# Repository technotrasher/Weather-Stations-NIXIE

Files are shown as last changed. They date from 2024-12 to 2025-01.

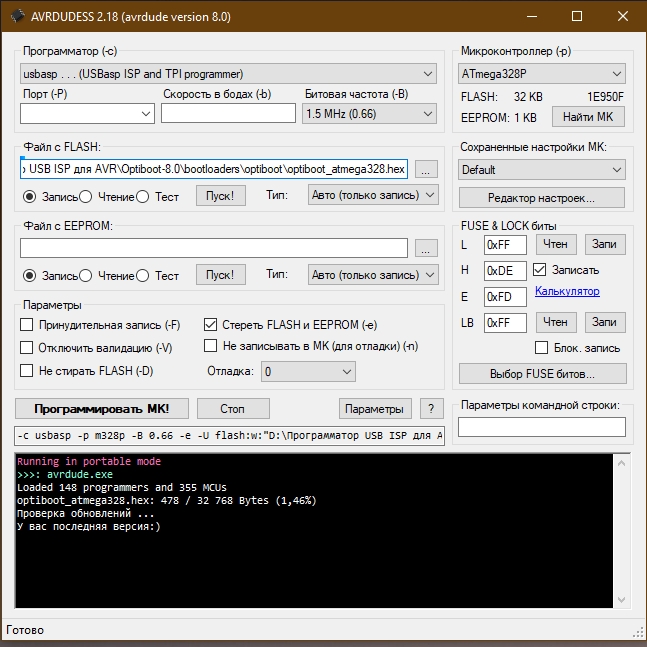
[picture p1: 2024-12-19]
328P_optiboot/1.jpg

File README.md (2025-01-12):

Проект Часы на ГРИ - погодная станция.

Одна плата управления. универсальна под разные лампы. и платы для ламп.

платы тут https://easyeda.com/technotrasher/nixie_clock_pcb_in14

Функции: показ времени :), отображение температуры, влажности, давления и СО2. Возможность подключения выносного датчика DS18B20. основной - BME280.

С помощью ESP-M2 есть возможность синхронизации времени через WI-FI.

Будильник с мерзким звуком. звук нажатия кнопок. звук можно настроить в самом скетче. буззер ставить БЕЗ ГЕНЕРАТОРА на 5В! (отличные результаты с LD-BZPN-3510)

Посветка из 6 программируемых свветодиодов ws2812. устанавливаются на платы для ламп. своих посадочных мест не имеют. можно размещать по своему усмотрению. RGB не подходят!!!!

7 вариантов работы:

Клик по кнопке btnUp переключает режимы подсветки ламп

    - выключена
    
    - выключена, но данные с датчиков подсвечиваются
    
    - постоянный свет
    
    - палитра PartyColors
    
    - палитра RainbowStripeColors
    
    - палитра CloudColors
    
Так же в режимах отображения информации своя подсветка:

    - режим отображения СО2 - ppm больше 1000, то цвет ярко красный
    
    - отображение давления - синий цвет всех светодиодов
    
    - влажность - ниже 32% цвет зеленовато-желтый, 32-40 - желтый, больше 40 - изумрудный
    
    - температура ниже нуля - цвет первых двух светодиодов синий
    
    - температура с датчика выносного DS - первый светодиод голубой.
      
   Есть эффекты переключения цифр:
   
Клик по кнопке btnDwn переключает режимы перелистывания цифр отображения часов и минут во время их смены:

      - Без эффекта
      
      - Плавное угасание
      
      - Перемотка по порядку числа
      
      - Перемотка по катодам
      
      - Поезд
      
      - Резинка
      
      - Блики
      
      - Перемотка со смещением
      
 Клик по кнопке btnSet переключает режимы перелистывания цифр секунд:
 
      - Без эффекта
      
      - Плавное угасание
      
      - Перемотка по порядку числа
      
Удержание кнопки btnUp:

      - показ даты.
      
для возврата удержать кнопку повторно.

Так же присутствуют глюки и эффекты. не отключаются. проявляются рандомно.

    - поезд
    
    - перепад напряжения
    
    - перебор катодов
    
    - неизвестно что

Основная плата выполненна на  AT328p. B неё нужно прошить загрузчик. я рекомендую optiboot.

В папке 328P_optiboot программа, сам загрузчик и скрин с настройками.
Загружать через программатор и разъем ISP на плате. после чего загружать скетчи можно через arduino ide и разъем USB.
Как вариант загружать можно скетч и через программатор. как подсоединять программатор, как загружать скетч описывать не буду.
все есть в интернете

При прошивке скетча отключать модуль ESP с помощью джамперов. !!!!!!!!!!!!!!!!!!!!!

ESP-2M обязательно обновить версию ПО. 

https://wiki.sipeed.com/soft/maixpy/en/get_started/upgrade_esp8285_firmware.html

в папке programm_esp есть программа, скрин с настройками и само ПО.

для прошивки нужен конвертер USB-TTL CH340G. или любой другой подходящий.
после загрузки ПО обязательно перевести модуль в режим точки клиента WI-Fi командой AT+CWMODE_DEF=1
о работе с модулями ESP так же есть вся информация в интернете.

После сборки выставить потенциометр на середину! крайние положения не выставлять! после подключить лампы и контролируя напряжение
на конденсаторе установить 175-180В!!!

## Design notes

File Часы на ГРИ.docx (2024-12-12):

Часы на ГРИ (Газо-Разрядных Индикаторах) Версии V1 и V2 (1999 г.)

Инструкция по эксплуатации.

ВНИМАНИЕ! После включения не дотрагивайтесь до компонентов и токоведущих дорожек платы, схема находится под высоким напряжением порядка 180В. Данное напряжение требуется для питания ламповых индикаторов. Будьте внимательны, соблюдайте правило работы с высоким напряжением.

### Особенности

- Режим антиотравления катода (перед сменой минут происходит быстрый перебор всех цифр во всех лампах)
- Будильник
- Сигнал каждый час
- Отображение температуры и влажности
- Отображение давления в мм ртутного столба
- Отображение содержания СО2 в ppm (parts per million — частей на миллион — единица измерения концентрации) (только для версии v1)
- Для каждого отображения или его критического значения разработана своя световая индикация. Так – давление (синий цвет), температура-влажность: влажность меньше 32% – цвет тёмно-красный, от 32 до 40 % влажности желто-зелёный, больше 40% - изумрудно зелёный, содержание СО2 – белый цвет до 1200 ppm и красный более 1200 (СО2 только для версии v1)
- При включении прибора происходит перебор анодов и катодов индикаторов
- Ночная и дневная яркость, как подсветки, так и индикаторов
- Настройка времени и будильника
- Отключение, переключения режимов подсветки кнопкой
- Переключение эффектов смены цифр кнопкой (только для версии v2)

Газоразрядные индикаторы ИН-14 (ИН-12 для версии v2) производились в прошлом веке и использовались для отображения информации (цифровой, символьной), на основе тлеющего разряда. В настоящее время данные лампы используются для создания часов.

Часы имеют энергонезависимую память на модуле DS1302 RTC - в комплект входит батарейка CR2032, или акб для V1.

Управление часами происходит тремя кнопками. С помощью кнопки "SET (S для V2)" происходит перебор режимов. Переход часы, будильник, отображение времени – длительное нажатие (2 секунды). С помощью кнопок установки значения “+”,”-” происходит смена значения в том или ином режиме. Перемещение между индикаторами – краткое нажатие кнопки “SET” (менее 1 секунды). Тумблер, позиция вверх - включает сигнал будильника, вниз – отключает. Сигнал так же отключится при переходе часов в режим показа давления и т.д. Отключение/включение подсветки – длительное нажатие (2 секунды) кнопки “+” (для версии V1). Переключение режимов подсветки – нажатиями кнопки “L” (постоянный свет, градиент теплый, радуга, градиент холодный, отключение подсветки) для V2. Переключение режимов смены цифры – кнопка “E”, переключаемые режимы сопровождаются соответствующей индикацией. Режимы – перебор катодов, затухание, резинка, поезд, выключено.

Во время настройки времени – секунды продолжают идти!

Конструктивно устройство выполнено на двух печатных платах из фольгированного стеклотекстолита. Расстояние между соединенными платами – 15 мм. Не надавливайте на верхнюю плату с лампами во время работы прибора, это приведёт к КЗ!!!!

Раз в 30 минут, когда происходит смена знака, включается режим антиотравления катода ламп. В этот момент происходит перебор всех знаков в каждом индикаторе, что делает работу часов еще более эффектнее. Время перебора измеряется в миллисекундах и визуально не заметна.

Часы запрограммированы на различные эффекты, которые разбавят монотонное отображение времени на индикаторах. Эффекты – Глюк (яркостной дребезг индикатора, в том числе и точек), Поезд (убегание показаний индикации времени), Перебор индикаторов (перебор анодов и катодов, но в соответствии с установленной суточной яркостью). Время срабатывания эффектов задаётся неопределённо (rnd) - и станет сюрпризом.

При отключении часов от эл. питания и последующем включении – время не сбивается!!!

В задней стенке часов находятся датчики. Или датчик BME220 для V2

Часы запрещается эксплуатировать в запыленном и влажном (более 90% влажности) воздухе. А также избегать попадание воды на прибор.

Как заводить часы?

Изначально они заводятся на 35-40 оборотов. Современные механизмы сделаны таким образом, что часы «перезавести» невозможно. Но это не значит, что крутить заводную головку можно до фанатизма. При полном заводе они проработают 36-40 часов в зависимости от механизма.

Монтаж часов:

1 Освободите молоточки от упаковки

2 Подвесьте маятник

Достаньте маятник из упаковки, снимите защитную пленку, аккуратно подвесьте его на крючок, который находится за механизмом.

3 Подвесьте гири

Освободите цепи от упаковки. Часы должны стоять прямо, чтобы избежать цепи соскочили с механизма. Если у часов три гири, необходимо последовательно подвесить их на цепи. Если гирь нет, значит их украли.

4 Запустите механизм

Завести механизм часов, аккуратно раскачивая маятник. Через несколько минут маятник обретет нужную скорость, и Вы услышите регулярных ход часов «тик-так».

Не забывайте кормить кукушку!

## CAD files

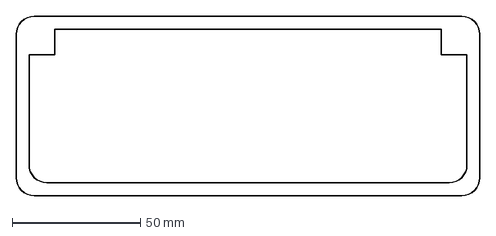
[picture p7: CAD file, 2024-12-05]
model/корпус12/кольцо лицо 4.dxf
181.0 x 70.0 mm

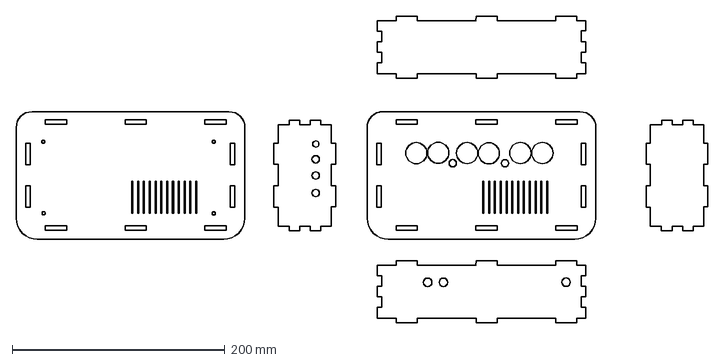
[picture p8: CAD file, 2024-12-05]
model/корпус3/корпус3.dxf
650.3 x 288.2 mm

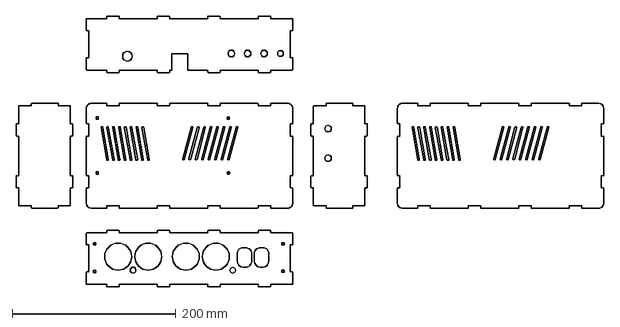
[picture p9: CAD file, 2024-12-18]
model/корпус4/корпус 4.dxf
717.6 x 330.7 mm

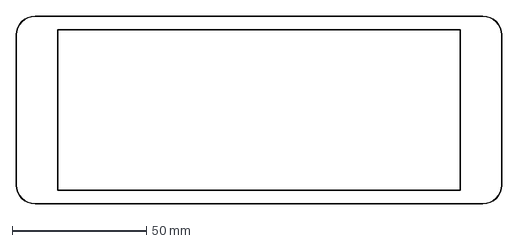
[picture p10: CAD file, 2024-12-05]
model/корпус12/кольцо лицо 1.dxf
181.0 x 70.0 mm

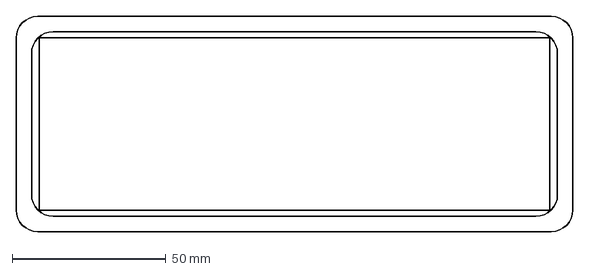
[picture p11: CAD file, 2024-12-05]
model/корпус12/кольцо лицо главное.dxf
181.0 x 70.0 mm

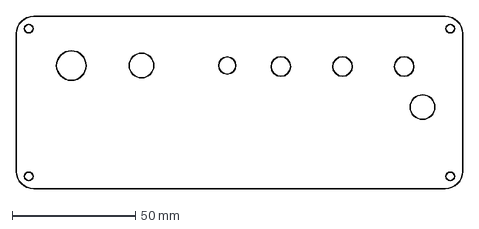
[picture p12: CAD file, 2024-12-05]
model/корпус12/крышка зад.dxf
181.0 x 70.0 mm

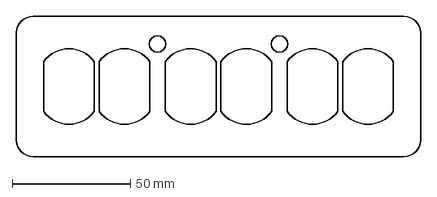
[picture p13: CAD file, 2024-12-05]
model/корпус12/панель перед.dxf
170.9 x 59.4 mm

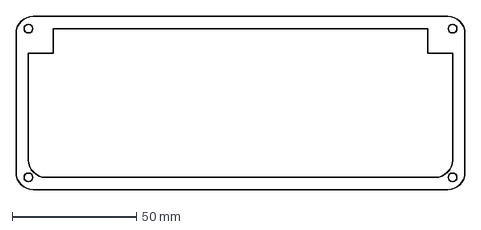
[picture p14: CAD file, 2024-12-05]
model/корпус12/кольцо лицо жопа.dxf
181.0 x 70.0 mm

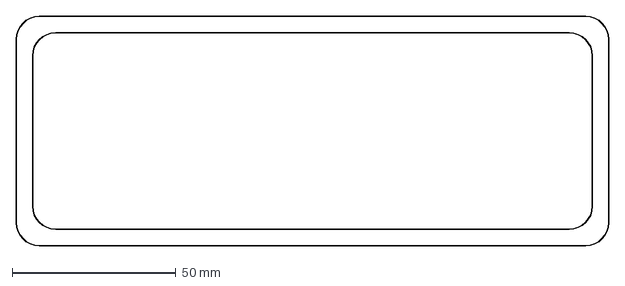
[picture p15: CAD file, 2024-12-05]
model/корпус12/кольцо лицо 6.dxf
181.0 x 70.0 mm

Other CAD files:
model/korpus3.dwg
model/корпус12/кольцо лицо 1 v3.f3d
model/корпус12/кольцо лицо 4 v3.f3d
model/корпус12/кольцо лицо 6 v3.f3d
model/корпус12/кольцо лицо главное v3.f3d
model/корпус12/кольцо лицо жопа v3.f3d
model/корпус12/крышка зад v6.f3d
model/корпус12/панель перед v9.f3d
model/корпус3/korpus3 v29.f3d
model/корпус4/корпус 4 v22.f3d

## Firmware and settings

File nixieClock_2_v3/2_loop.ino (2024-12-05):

void loop() {
  if (dotTimer.tick() && (stat_mode == Clock || stat_mode == ClockSet || stat_mode == AlarmSet || stat_mode == DataSet || stat_mode == DataSetY)) calculateTime();                  // каждые 500 мс пересчёт и отправка времени
  if (newTimeFlag && stat_mode == Clock) flipTick(); //включение эффектов при переходе через минуту и час
  if (newTimeFlagsec && stat_mode == Clock) Ticksec(); // эффект секунды                                                                                                                                // перелистывание цифр
  dotBrightTick();                                                                                                                                                                  // плавное мигание точки
  if ((SHOW_GL && stat_mode == Clock) || stat_mode == Temperature || stat_mode == Pressure || stat_mode == CO2) glitchTick();                                                       // глюки
  buttonsTick();                                                                                                                                                                    // кнопки
  settingsTick();                                                                                                                                                                   // настройки
  pwm();                                                                                                                                                                            // данные с датчика СО2 MHZ19
  if (SHOW_ESP && !alm_flag && ef_flag && ESPTimer.tick()) realtime();                                                                                                              // синхронизация времени через WIFI
  if (stat_mode > 8 || curMode > 4) resetFunc();                                                                                                                                    // перезагрузка при глюке ака костыль  4 режим
  if ((SHOW_TEMP_HUM || SHOW_TEMP_DS) && !alm_flag && ef_flag && stat_mode != AlarmSet && stat_mode != ClockSet && stat_mode != DataSet && stat_mode != DataSetY) stat_modeTick();  //температура влажность
  if (SHOW_CO2 && !alm_flag && ef_flag && stat_mode != AlarmSet && stat_mode != ClockSet && stat_mode != DataSet && stat_mode != DataSetY) stat_modeTickCO();                       // СО2
  if (SHOW_PRES && !alm_flag && ef_flag && stat_mode != AlarmSet && stat_mode != ClockSet && stat_mode != DataSet && stat_mode != DataSetY) stat_modeTickP();                       // отображать давление
  if (SHOW_TR && !alm_flag && ef_flag && stat_mode != AlarmSet && stat_mode != ClockSet && stat_mode != DataSet && stat_mode != DataSetY) train_Event();                            //поезд.
  if (SHOW_TEST && !alm_flag && ef_flag && stat_mode != AlarmSet && stat_mode != ClockSet && stat_mode != DataSet && stat_mode != DataSetY) TestTimerI();                           //перебор индикаторов. тут можно отключить
  if (stat_mode == Clock && !alm_flag) {
    LEDsFromColors();  // установить подсветку
  }
}

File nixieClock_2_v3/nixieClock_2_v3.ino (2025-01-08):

/*
  Скетч к проекту "Часы на ГРИ версия 3.5"
  платы тут https://easyeda.com/technotrasher/nixie_clock_pcb_in14
*/

/*
                       При прошивке скетча отключать модуль ESP!!!!!!!!!!!!!!!!!!!!!!
  Управление:
  - Настройка времени:
    - Левая кнопка - выбор, остальные "больше" и "меньше"
    - Удержать "выбор" первый раз btnSet - настройка времени
    - Клик по "выбору" btnSet - смена настройки часы/минуты
    - Клик "больше" и "меньше" - изменение времени
    - Удержать "выбор" второй раз - настройка будильника
    - Левая кнопка - выбор, остальные "больше" и "меньше"
    - Удержать "выбор" третий раз - установка даты и месяца
    - Удержать "выбор" четвертый раз - установка года
    - Удержать "выбор" btnSet - настройка времени
    - Клик по "выбору" btnSet - смена настройки часы/минуты
    - Клик "больше" и "меньше" - изменение времени
    - Удержать "выбор" - возврат к показу времени
    - Удержание "больше" - отображение даты. вид - день. месяц. день недели. для выхода нажать и удержать повторно

    В модуле ESP в строке 58 указать свои настройки. имя точки вайфай и пароль к точке доступа. кавычки не трогать.
    В библиотеке wire - если на плате нет подтяжки пинов A4 A5 к vcc через резисторы 4.7кОм, то заменить строку
  PORTC &= 0xCF; //отключаем подтяжку SDA и SCL
  на строку
  PORTC |= 0x30; //включаем подтяжку SDA и SCL

  Подсветка
  1. режим отображения СО2 - ppm больше 1000, то цвет ярко красный
  2. отображение давления - синий цвет всех светодиодов
  3. Влажность - ниже 32% цвет зеленовато-желтый, 32-40 - желтый, больше 40 - изумрудный
  4. температура ниже нуля - цвет первых двух светодиодов синий
  5. температура с датчика выносного DS - первый светодиод голубой
 

  - Управление эффектами В РЕЖИМЕ ЧАСОВ:
    - Клик по кнопке btnUp переключает режимы подсветки ламп
    - выключена
    - выключена, но данные с датчиков подсвечиваются
    - постоянный свет
    - палитра PartyColors
    - палитра RainbowStripeColors
    - палитра CloudColors
    - Клик по кнопке btnDwn переключает режимы перелистывания цифр
      - Без эффекта
      - Плавное угасание
      - Перемотка по порядку числа
      - Перемотка по катодам
      - Поезд
      - Резинка
      - Блики
      - Перемотка со смещением

  Удержание кнопки btnUp
  - показ даты.
  для возврата удержать кнопку повторно

  Удержание кнопки btnDown
  - отключает запрос времени из интернета через модуль ESP (изначально включено) 0 = SHOW_ESP - выкл. 1 = SHOW_ESP - вкл
 
  Двойной клик по btnUP - смена часового пояса. работает только при работе модуля ESP
  после двойного нажатия - сигнал длиннее прозвучит (1 = esptime - лето 0 = esptime - зима)
  Одинарный клик по btnSet - включение/отключение эффекта секунд без эффекта, угасание, перемотка


*/
// ************************** НАСТРОЙКИ **************************
#define DUTY 190  // скважность ШИМ. От скважности зависит напряжение! у меня 175 вольт при значении 180 и 145 вольт при 120

// ======================= ЭФФЕКТЫ =======================
// эффекты перелистывания часов
uint8_t FLIP_EFFECT = 1;
// Выбранный активен при запуске и меняется кнопками
// 0 - нет эффекта
// 1 - плавное угасание и появление (рекомендуемая скорость: 100-150)
// 2 - перемотка по порядку числа (рекомендуемая скорость: 50-80)
// 3 - перемотка по порядку катодов в лампе (рекомендуемая скорость: 30-50)
// 4 - поезд (рекомендуемая скорость: 50-170)
// 5 - резинка (рекомендуемая скорость: 50-150)
// 6 - блики (рекомендуемая скорость: 80-250)
uint8_t FLIP_SPEED[] = { 0, 100, 100, 50, 70, 70, 150, 70 };  // скорость эффектов, мс (количество не меняй) 0, 130, 50, 40, 70, 70, 200, 90

// эффекты подсветки
uint8_t BACKL_MODE = 1;
// Выбранный активен при запуске и меняется кнопками
// 0 - выключена полностью
// 1 - выключена, но работает при отображении СО2 и т.д.
// 2 - постоянный свет
// 3 - радуга
// 4 - градиент
// 5 - рандомный цвет
// 6 - волна
// 7 - дыхание
// 8 - бегущий огонь

// =======================  ЯРКОСТЬ =======================
#define NIGHT_START 22  // час перехода на ночную подсветку (BRIGHT_N)
#define NIGHT_END 8     // час перехода на дневную подсветку (BRIGHT)

#define INDI_BRIGHT 22   // яркость цифр дневная (1 - 24) !на 24 могут быть фантомные цифры! 23
#define INDI_BRIGHT_N 7  // яркость ночная (1 - 24) 5
uint8_t SHOW_SEC = 0;   // переключение эффектов секунд. 0 -  выключен

#define DOT_BRIGHT 70    // яркость точки дневная (1 - 255) 80
#define DOT_BRIGHT_N 25  // яркость точки ночная (1 - 255)

#define BACKL_BRIGHT 80    // макс. яркость подсветки дневная (0 - 255) 80
#define BACKL_BRIGHT_N 30  // макс. яркость подсветки ночная (0 - 255, 0 - подсветка выключена)
//https://colorscheme.ru/color-converter.html

// =======================  ГЛЮКИ =======================
#define GLITCH_MIN 30   // минимальное время между глюками, с
#define GLITCH_MAX 120  // максимальное время между глюками, с

#define train_MIN 300  // минимальное время между поездом, с 180
#define train_MAX 600  // максимальное время между поездом, с 300

#define test_MIN 1000  // минимальное время между перебором индикаторов, с 1000
#define test_MAX 2000  // максимальное время между перебором индикаторов, с  20

// ======================  МИГАНИЕ =======================
#define DOT_TIME 500  // время мигания точки, мс
#define DOT_TIMER 25  // шаг яркости точки, мс

// ==================  АНТИОТРАВЛЕНИЕ ====================
#define BURN_TIME 5     // период обхода индикаторов в режиме очистки, мс
#define BURN_LOOPS 6    // количество циклов очистки за каждый период
#define BURN_PERIOD 39  // период антиотравления, минут


// *********************** ДЛЯ РАЗРАБОТЧИКОВ ***********************
uint8_t FLIP_EFFECT_NUM = sizeof(FLIP_SPEED);  // количество эффектов

// --------- БУДИЛЬНИК ---------
#define ALM_TIMEOUT 30  // таймаут будильника
#define FREQ 900        // частота писка будильника

// ************************** НАСТРОЙКИ **************************
#define TEMP_TIME 7      // время (с), НА которое отображаются температура и влажность
#define TEMP_PRES 202    // время (с), через которое отображается давление 202
#define TEMP_CO2 271     // время (с), через которое отображается содержание СО2 //330 271
#define CLOCK_TIME 120   // время (с), через которое отображаются температура и влажность
#define SHOW_TEMP_HUM 1  // 0 - не показывать температуру и вл., 1 - показывать
#define SHOW_PRES 1      // 0 - не показывать давление, 1 - показывать
#define SHOW_CO2 1       // 0 - не показывать CO2, 1 - показывать
#define SHOW_TEMP_DS 0   // 0 - не показывать температуру с датчика DS18B20, 1 - показывать
#define SHOW_TR 1        // 0 - не показывать эффект поезд
#define SHOW_TEST 1      // 0 - перебор индикаторов
#define SHOW_GL 1        // 0 - глюк

// ******************************ESP ******************************
bool SHOW_ESP = 1;   // включение запроса от ESP  установить 1 для включения
#define ESP_TIME 3600  // время (с) время опроса ESP 1 час - 3600 с, 610 - 10 мин, 10800 - 3 часа
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
